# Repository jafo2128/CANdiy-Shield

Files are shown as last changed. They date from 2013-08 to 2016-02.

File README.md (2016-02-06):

# CANdiy-Shield
The CANdiy-Shield is a plug-on module for Arduino/Genuino with CAN-Bus (Controller Area Network) connectivity.

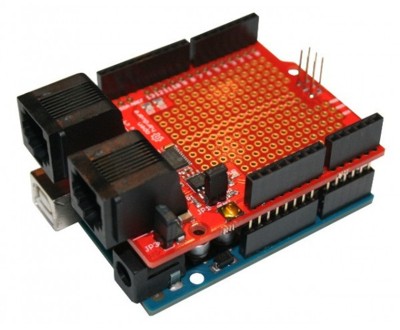
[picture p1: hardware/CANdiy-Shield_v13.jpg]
CANdiy-Shield (http://www.watterott.com/en/Arduino-CANdiy-Shield)


## Shop
* [CANdiy-Shield](http://www.watterott.com/en/Arduino-CANdiy-Shield)
* [Railuino Components](http://www.watterott.com/en/Railuino-components)
* [OBD2-Connector](http://www.watterott.com/en/OBD2-Connector-With-PCB)

## Features
* Microchip MCP2515 CAN Controller (SPI)
* Microchip MCP2562 CAN Transceiver (CANdiy-Shield v1.x: MCP2551)
* Switchable between 3V3 or 5V logic level
* 2 CAN connectors (RJ45)
* Prototyping Area
* Compatible with all Arduino/Genuino Boards (SPI connection via 6-Pin ISP connector)

## Hardware and Software
* [Schematics + Layout](https://github.com/watterott/CANdiy-Shield/tree/master/hardware)
* [Arduino Library and Examples](https://github.com/watterott/Arduino-Libs)

## Projects
* Railuino (Maerklin Model Railways): http://code.google.com/p/railuino/
  [German Documentation](https://railuino.googlecode.com/files/2013-08-01-Railuino-Directors-Cut.pdf),
  [German Forum](http://www.stummiforum.de/viewtopic.php?t=90072),
  [German Magazine Article](https://shop.heise.de/katalog/ct-hardware-hacks-1-2013),
  [English Documentation](http://www.yaasan.mints.ne.jp/railuino.html),
  [French Documentation](http://mchobby.be/wiki/index.php?title=Railuino)
* Mechanic (OBD-II Interface): http://code.google.com/p/mechanic/
* Electricity on Tap: http://www.terabatt.com/makerscorner.html
* WikiCAN (OBD On-Board-Diagnostics): http://www.wikican.uni-bayreuth.de/wikican/index.php?title=WikiCAN-Arduino
* MERG CBUS (Model Railways): http://www.oscale.net/cbus http://www.merg.org.uk/merg_resources/cbus.php

Finally words from us Archivers and Developers.. 

##### Donate

People from time to time wish to donate a little money. Donating won't get you anything special, other than a warm feeling inside, and possibly urge me to produce more freely available material for interesting projects. You can donate via [PayPal](https://www.paypal.com), just click [donate](https://www.paypal.com/cgi-bin/webscr?cmd=_s-xclick&hosted_button_id=3PXVSLXFBS45E) button available below - it will redirect you to the secured PayPal page where you can provide donation amount (there is no minimal value). Any donations are apreciated greatly, and we thank you all in advance for your support along the ways..



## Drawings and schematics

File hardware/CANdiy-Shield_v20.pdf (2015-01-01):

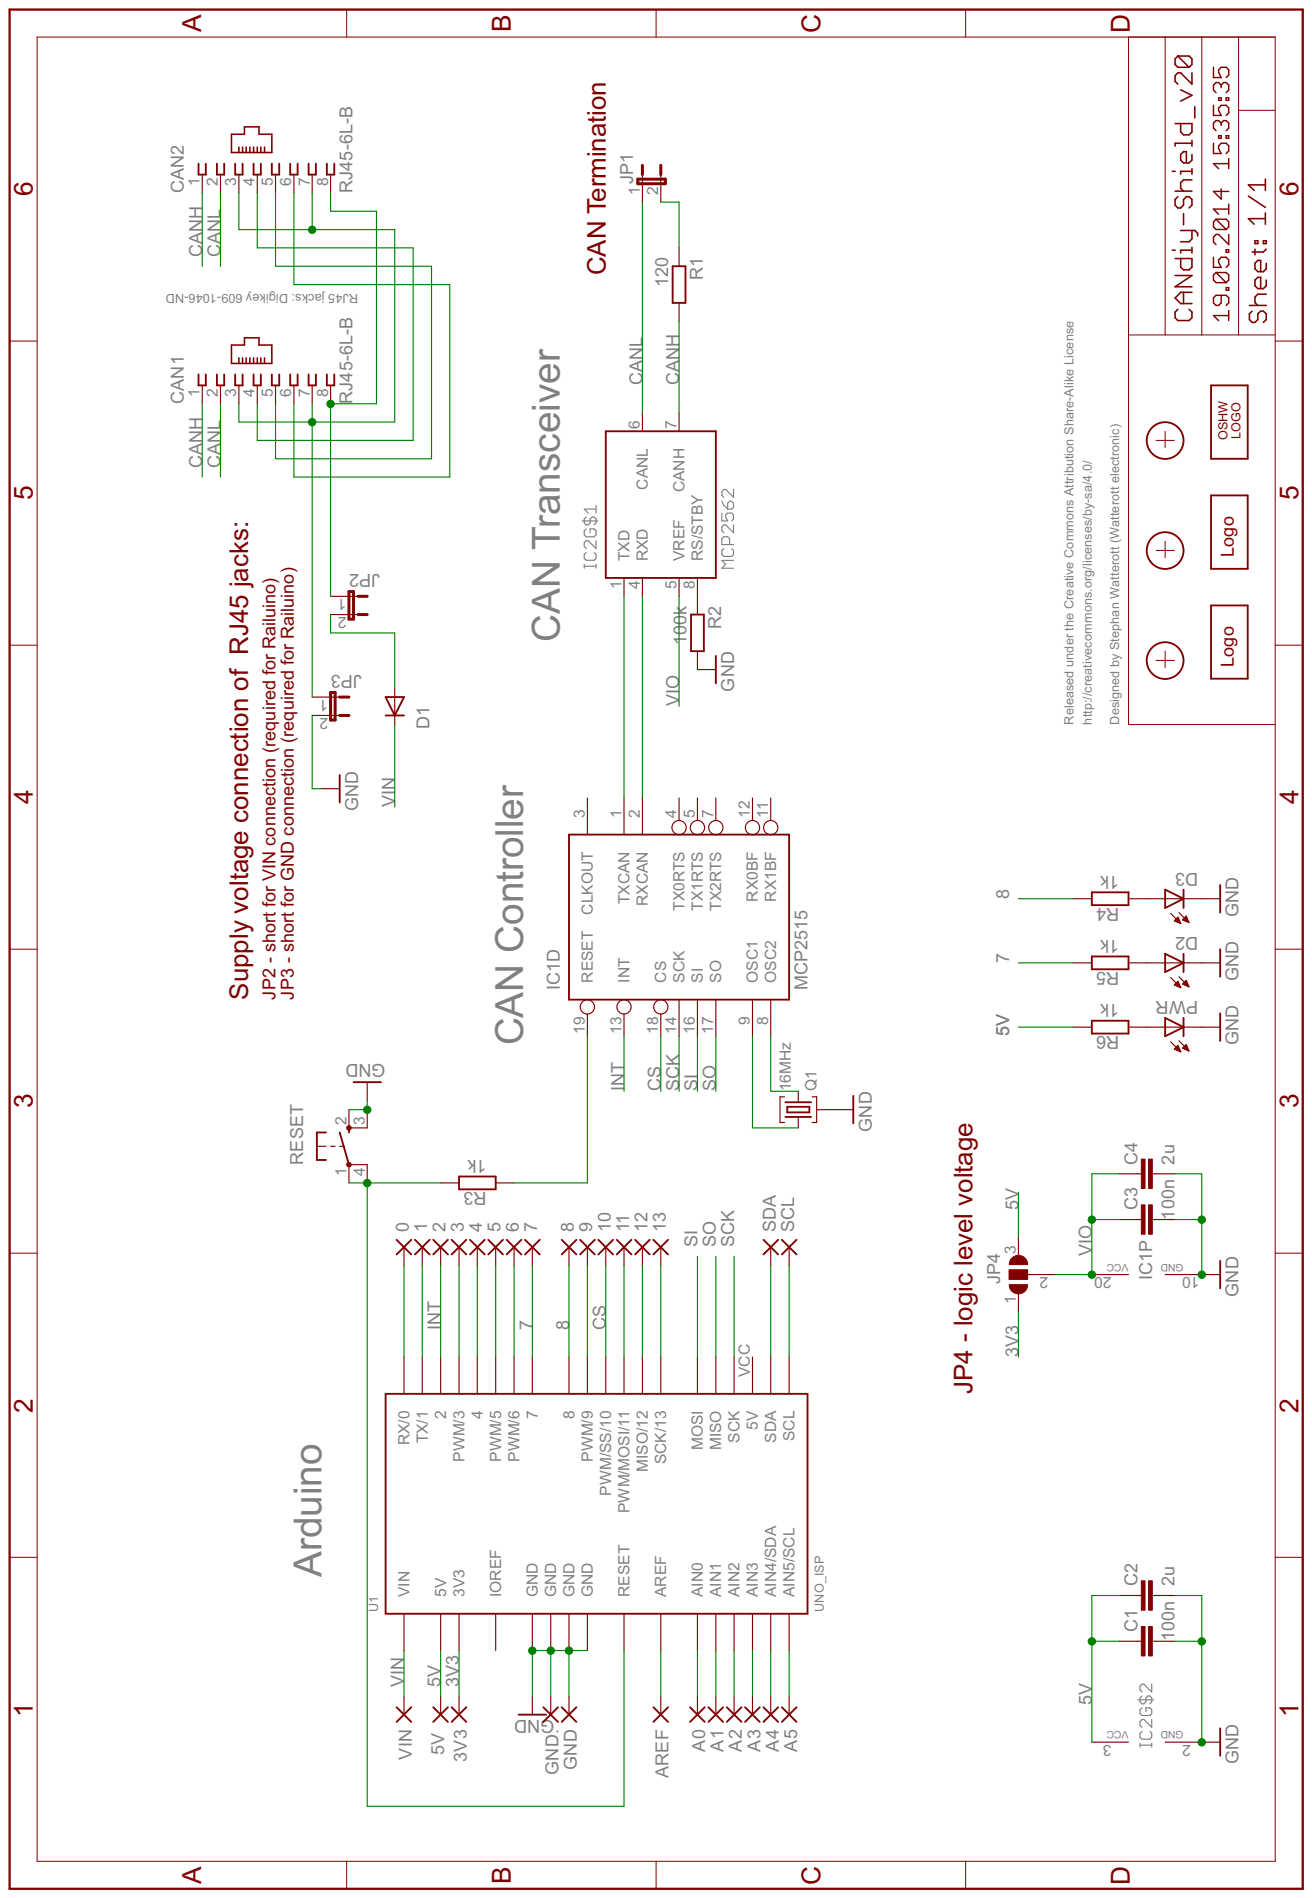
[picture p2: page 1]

DN- 6401- 906 yeki gi D: skcaj 54J RDNG DNG GND 120 RJ45-6L-B RJ45-6L-B 100n 2u GND 100k GND GNDk1 GNDk1 GNDk1 GND 16MHz MCP2515 100n GND 2uk1 Released under the Creative Commons Attribution Share-Alike License http://creativecommons.org/licenses/by-sa/4.0/ Designed by Stephan Watterott (Watterott electronic) Arduino CAN Controller CAN Transceiver /STBY RESET 1 23 4 CANH 7 CANL 6 RS 8 RXD 4 TXD 1 VREF 5 CCV DNG 3 2 R1 CAN2 12345678 CAN1 12345678 C1 C2 R2 JP1 12 2PJ 123PJ 12 012345678910111213SDA SCL A0A1A2A3A4A5 AREF VIN GND GND. 3V3 3D 4R R WP 6R 2D 5R D1 U1 UNO_ISP RX/0 TX/12 AIN0 PWM/34 PWM/5 PWM/678 PWM/9 PWM/SS/10 PWM/MOSI/11 MISO/12 SCK/13 AIN1 AIN2 AIN3 AIN4/SDA AIN5/SCL 5VVIN 3V3 AREF RESET SDA SCL IOREF GND GND GND MOSI MISO SCK GND 5V VCC Q1 IC1D CLKOUT 3 CS 18 INT 13 OSC1 9 OSC2 8 RESET 19 RX0BF 12 RX1BF 11 RXCAN 2 SCK 14 SI 16 SO 17 TX0RTS 4 TX1RTS 5 TX2RTS 7 TXCAN 1 CCV DNG IC1P 02 01 C3 3 1 2 JP4 C4 3R 5V 5V 5V 5V 5V VIN VIN CS CS SCK SCK SI SI SO SO CANH CANH CANH CANL CANL CANL 8 8 INT INT 3V3 3V3 7 7 VIO VIO CAN Termination Supply voltage connection of RJ45 jacks: JP3 - short for GND connection (required for Railuino) JP2 - short for VIN connection (required for Railuino) JP4 - logic level voltage ABCD 1 2 3 4 5 6 ABCD 1 2 3 4 5 6 OSHW LOGO Logo Logo

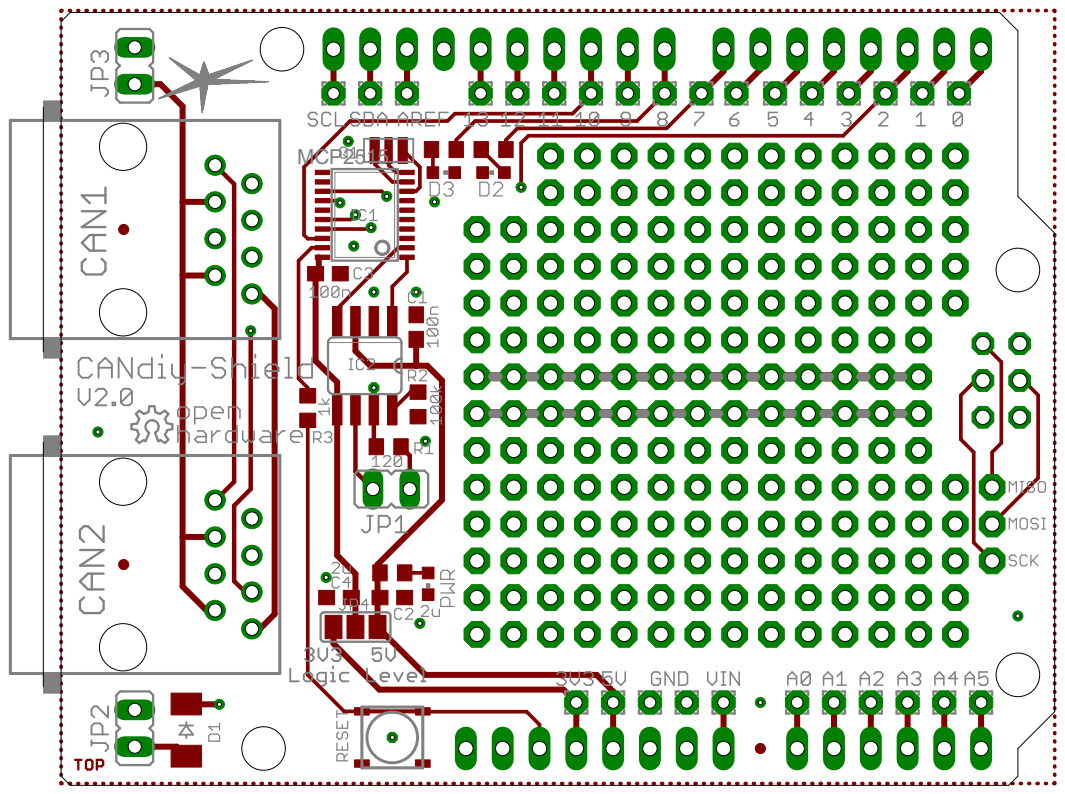
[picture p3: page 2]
MCP2515

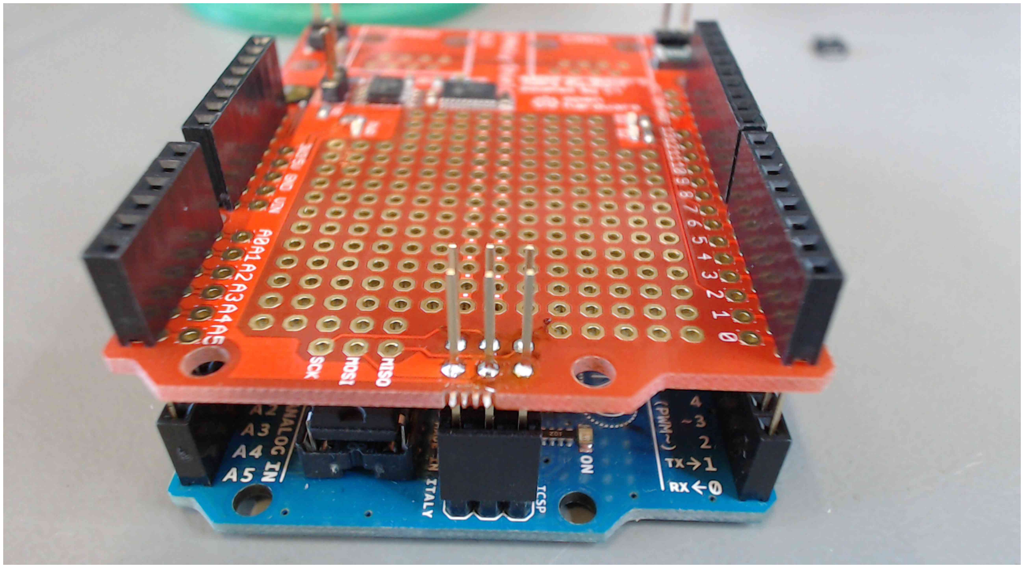
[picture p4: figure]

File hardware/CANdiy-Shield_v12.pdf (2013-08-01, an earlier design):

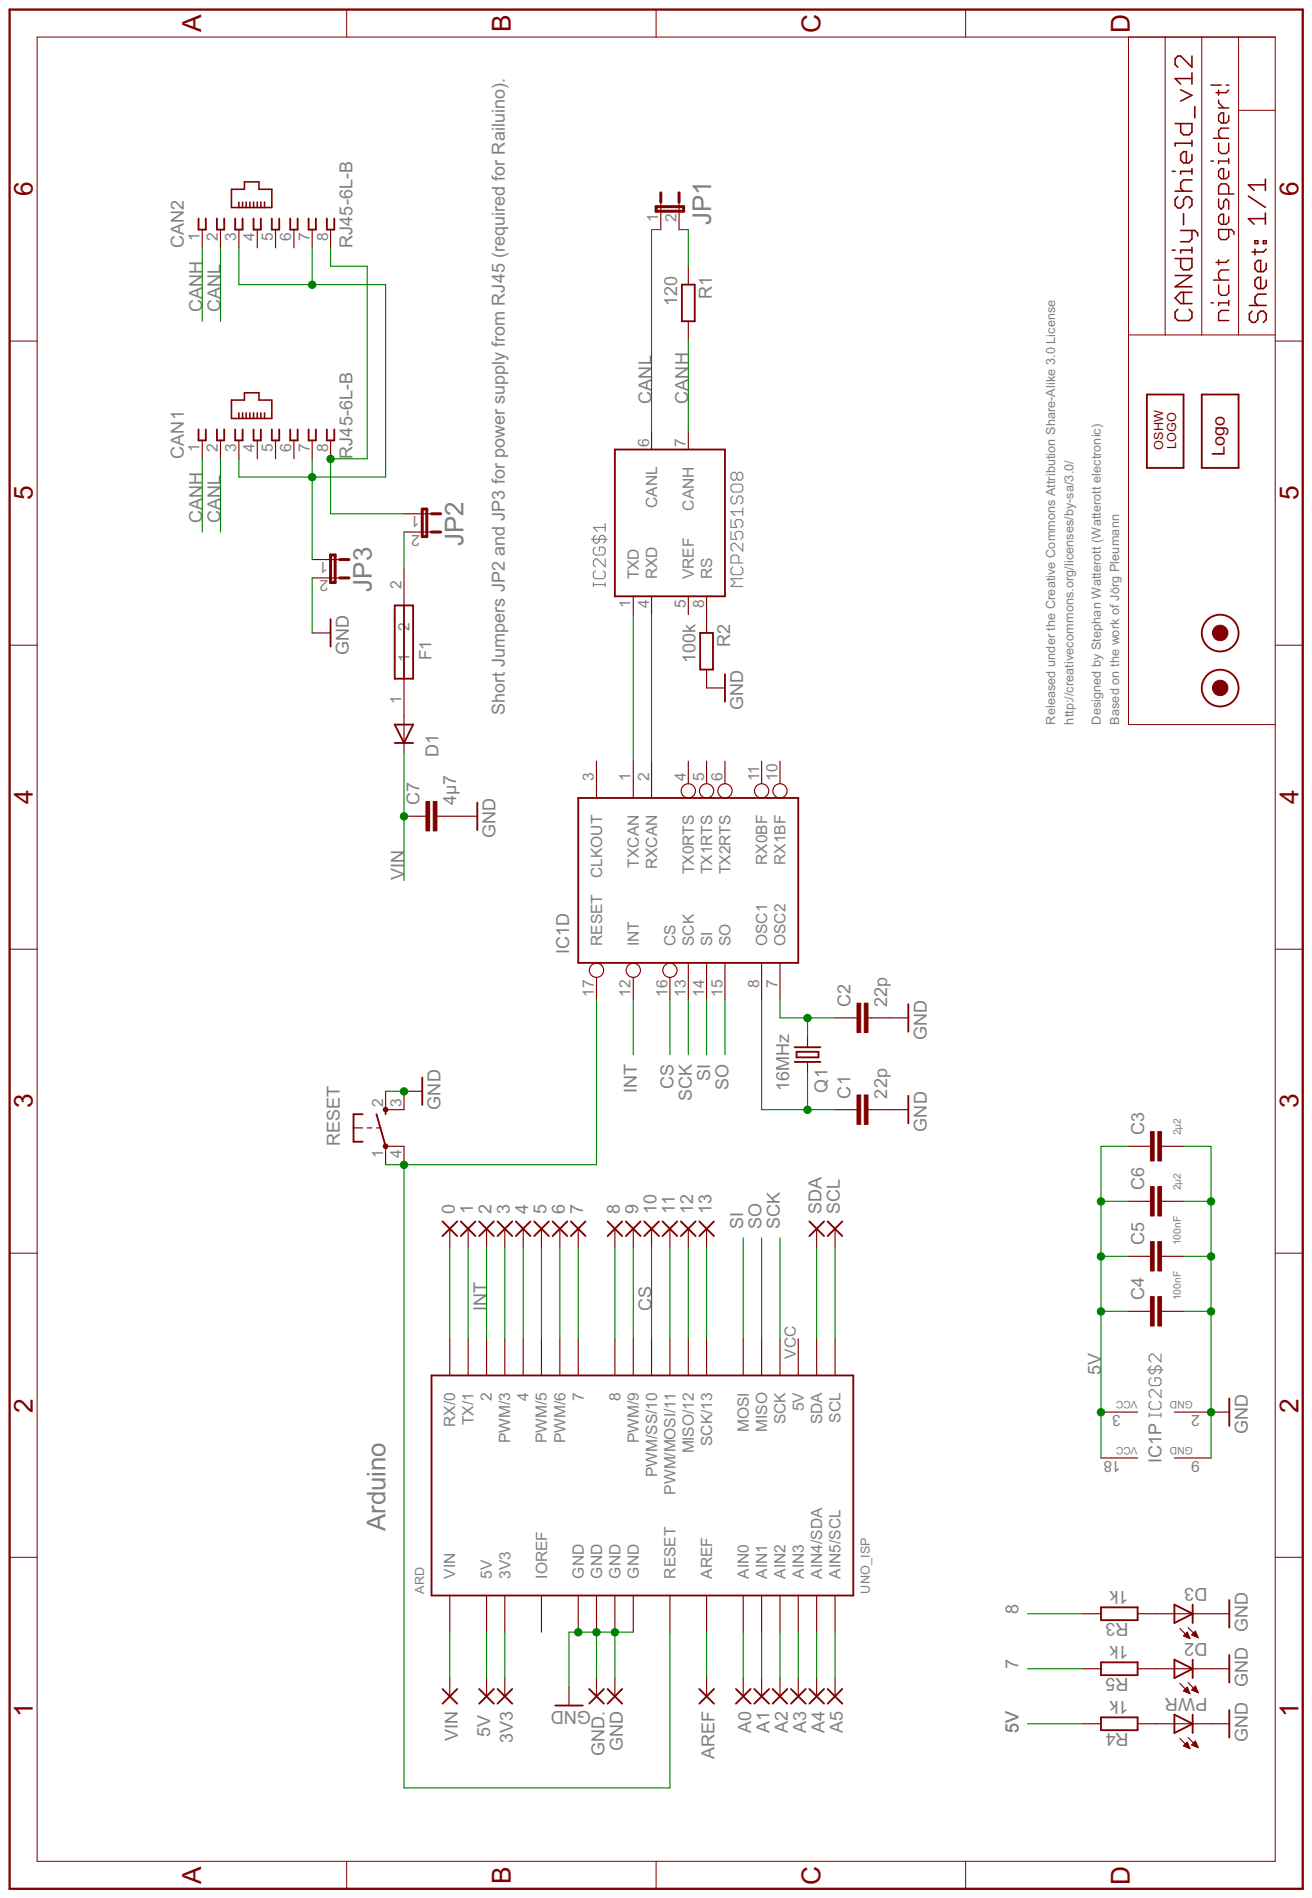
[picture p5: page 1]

GND GND 120 RJ45-6L-B RJ45-6L-B 16MHz 22p 22p 2µ2 100nF 100nF 2µ2 GND GND 100k GND DNG GNDk1 GNDk1 GNDk1 4µ7 GND GND Released under the Creative Commons Attribution Share-Alike 3.0 License http://creativecommons.org/licenses/by-sa/3.0/ Designed by Stephan Watterott (Watterott electronic) Arduino F1 Based on the work of Jörg Pleumann RESET 1 23 4 IC1D CLKOUT 3 CS 16 INT 12 OSC1 8 OSC2 7 RESET 17 RX0BF 11 RX1BF 10 RXCAN 2 SCK 13 SI 14 SO 15 TX0RTS 4 TX1RTS 5 TX2RTS 6 TXCAN 1 CANH 7 CANL 6 RS 8 RXD 4 TXD 1 VREF 5 CCV DNG 3 2 R1 CAN2 12345678 CAN1 12345678 Q1 C1 C2 C3 C4 C5 C6 CCV DNG IC1P 81 9 R2 12JP1 12 JP2 12 JP3 012345678910111213SDA SCL A0A1A2A3A4A5 AREF VIN GND GND. 3V3 3D 3R R WP 4R 2D 5R C7 D1 1 1 2 2 ARD UNO_ISP RX/0 TX/12 AIN0 PWM/34 PWM/5 PWM/678 PWM/9 PWM/SS/10 PWM/MOSI/11 MISO/12 SCK/13 AIN1 AIN2 AIN3 AIN4/SDA AIN5/SCL 5VVIN 3V3 AREF RESET SDA SCL IOREF GND GND GND MOSI MISO SCK GND 5V VCC 5V 5V 5V VIN CS CS SCK SCK SI SI SO SO CANH CANH CANH CANL CANL CANL 8 INT INT 7 ABCD 1 2 3 4 5 6 ABCD 1 2 3 4 5 6 OSHW LOGO Logo Short Jumpers JP2 and JP3 for power supply from RJ45 (required for Railuino).

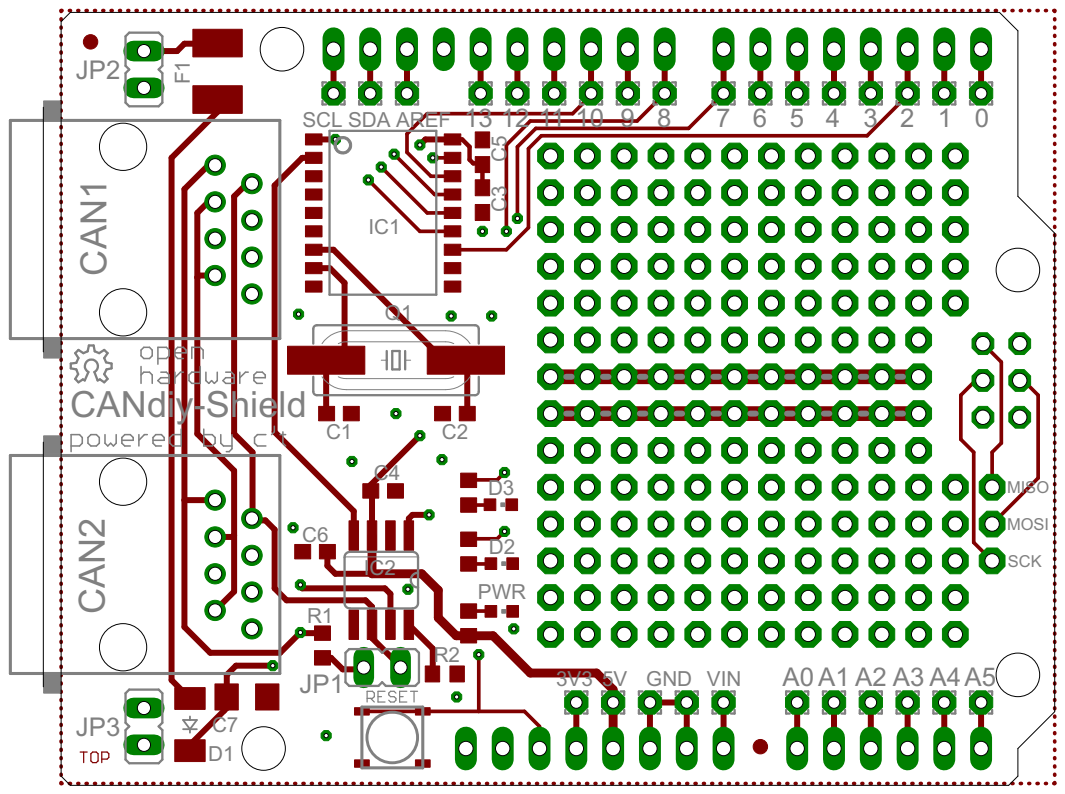
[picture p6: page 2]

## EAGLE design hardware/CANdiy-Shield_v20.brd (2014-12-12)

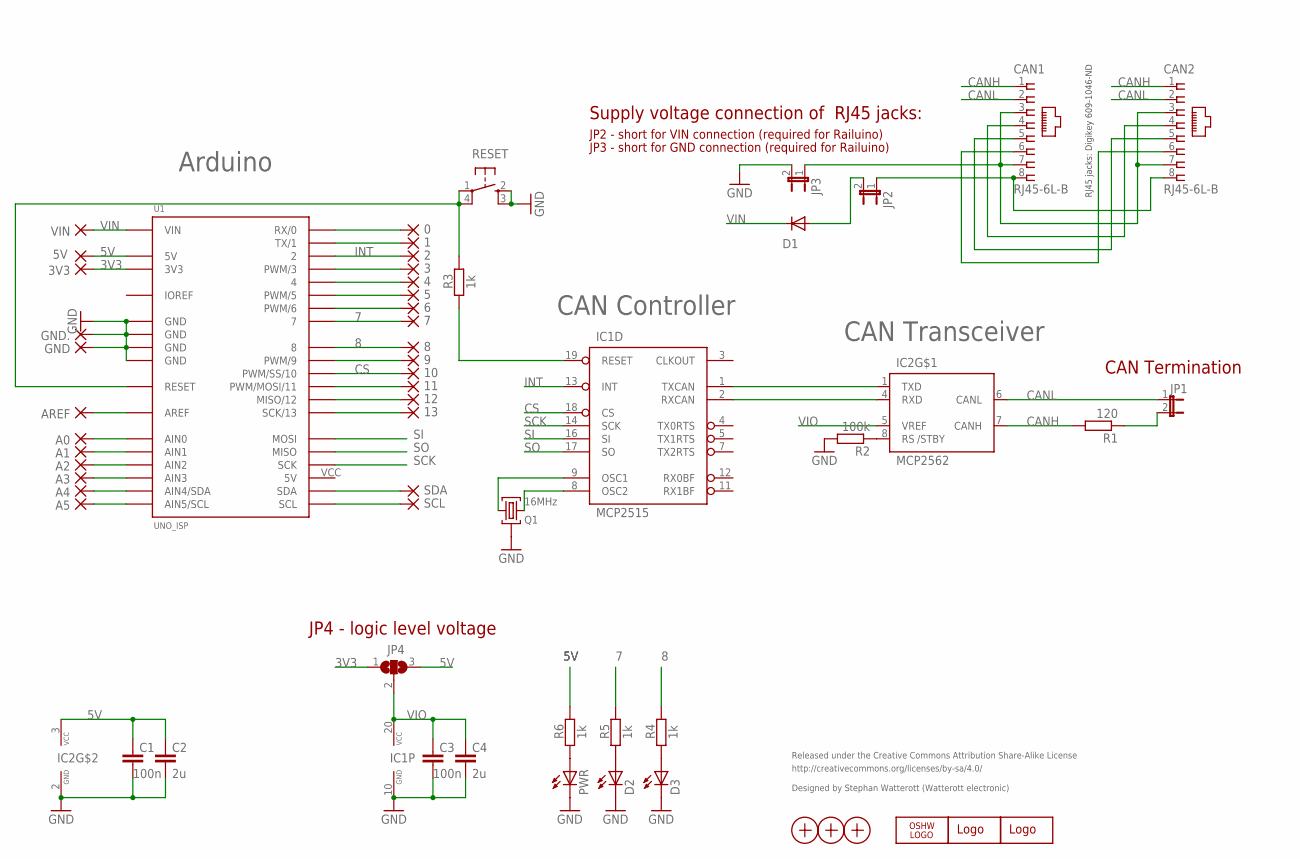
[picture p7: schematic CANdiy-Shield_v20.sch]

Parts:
0, 1, 2, 3, 3V3, 4, 5, 5V, 6, 7, 8, 9, 10, 11, 12, 13: 1,6/0,8
A0, A1, A2, A3, A4, A5: 1,6/0,8
AREF: 1,6/0,8
C1, C3: 100n; C0603
C2, C4: 2u; C0603
CAN1, CAN2: RJ45-6L-B; RJ45-NO-SHIELD
D1: CGRM4001-G; SOD-123_MINI-SMA
D2, D3: LEDCHIPLED_0603; CHIPLED_0603
GND, GND.: 1,6/0,8
IC1: MCP2515; TSSOP20
IC2: MCP2562; SO08
JP1, JP2, JP3: JP1E; JP1
JP4: SJ2W; SJ_2
LOGO1: LOGO-SPARK_PLACE; SPARK_TPLACE
LOGO2: OSHW_LOGO_6MILX0100-NT; OSHW_6X100_NOTEXT
PWR: LEDCHIPLED_0603; CHIPLED_0603
Q1: 16MHz; SMD_OSC_35X15
R1: 120; R0603
R2: 100k; R0603
R3, R4, R5, R6: 1k; R0603
RESET: SW_SMDS; SW_SMD4
SCL: 1,6/0,8
SDA: 1,6/0,8
U1: UNO_ISP
U$1: WE-LOGO
VIN: 1,6/0,8
X1, X2, X3: PASSER

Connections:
0: 0.1, U1.0 (RX/0)
1: 1.1, U1.1 (TX/1)
3: 3.1, U1.3 (PWM/3)
3V3: 3V3.1, JP4.1, U1.3V3
4: 4.1, U1.4
5: 5.1, U1.5 (PWM/5)
5V: 5V.1, C1.1, C2.1, IC2.3 (VCC), JP4.3, R6.1, U1.5V
6: 6.1, U1.6 (PWM/6)
7: 7.1, R5.1, U1.7
8: 8.1, R4.1, U1.8
9: 9.1, U1.9 (PWM/9)
11: 11.1, U1.11 (PWM/MOSI/11)
12: 12.1, U1.12 (MISO/12)
13: 13.1, U1.13 (SCK/13)
A0: A0.1, U1.AIN0
A1: A1.1, U1.AIN1
A2: A2.1, U1.AIN2
A3: A3.1, U1.AIN3
A4: A4.1, U1.AIN4 (AIN4/SDA)
A5: A5.1, U1.AIN5 (AIN5/SCL)
AREF: AREF.1, U1.AREF
CANH: CAN1.1, CAN2.1, IC2.7 (CANH), R1.2
CANL: CAN1.2, CAN2.2, IC2.6 (CANL), JP1.1
CAN_RX: IC1.2 (RXCAN), IC2.4 (RXD)
CAN_TX: IC1.1 (TXCAN), IC2.1 (TXD)
CS: 10.1, IC1.18 (CS), U1.10 (PWM/SS/10)
GND: C1.2, C2.2, C3.2, C4.2, D2.C, D3.C, GND.1, GND..1, IC1.10 (GND), IC2.2 (GND), JP3.2, PWR.C, Q1.GND, R2.2, RESET.2 (S), RESET.3 (S1), U1.GND@1 (GND), U1.GND@2 (GND), U1.GND@3 (GND), U1.GND@4 (GND)
INT: 2.1, IC1.13 (INT), U1.2
IOREF: U1.IOREF
unnamed: IC1.19 (RESET), R3.2
unnamed: CAN1.8, CAN2.8, JP2.1
unnamed: IC2.8 (RS), R2.1
unnamed: CAN1.3, CAN1.7, CAN2.3, CAN2.7, JP3.1
unnamed: JP1.2, R1.1
unnamed: SCL.1, U1.SCL
unnamed: SDA.1, U1.SDA
unnamed: D3.A, R4.2
unnamed: PWR.A, R6.2
unnamed: D2.A, R5.2
unnamed: D1.A, JP2.2
unnamed: CAN1.4, CAN2.4
unnamed: CAN1.5, CAN2.5
unnamed: CAN1.6, CAN2.6
OSC1: IC1.9 (OSC1), Q1.1
OSC2: IC1.8 (OSC2), Q1.2
RESET: R3.1, RESET.1, RESET.4 (P1), U1.RST (RESET)
SCK: IC1.14 (SCK), U1.SCK
SI: IC1.16 (SI), U1.MOSI
SO: IC1.17 (SO), U1.MISO
VIN: D1.C, U1.VIN, VIN.1
VIO: C3.1, C4.1, IC1.20 (VCC), IC2.5 (VREF), JP4.2

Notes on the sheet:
Released under the Creative Commons Attribution Share-Alike License
http://creativecommons.org/licenses/by-sa/4.0/
Designed by Stephan Watterott (Watterott electronic)
Arduino
CAN Termination
Supply voltage connection of RJ45 jacks:
JP3 - short for GND connection (required for Railuino)
JP2 - short for VIN connection (required for Railuino)
RJ45 jacks: Digikey 609-1046-ND
CAN Controller
CAN Transceiver
JP4 - logic level voltage
/STBY

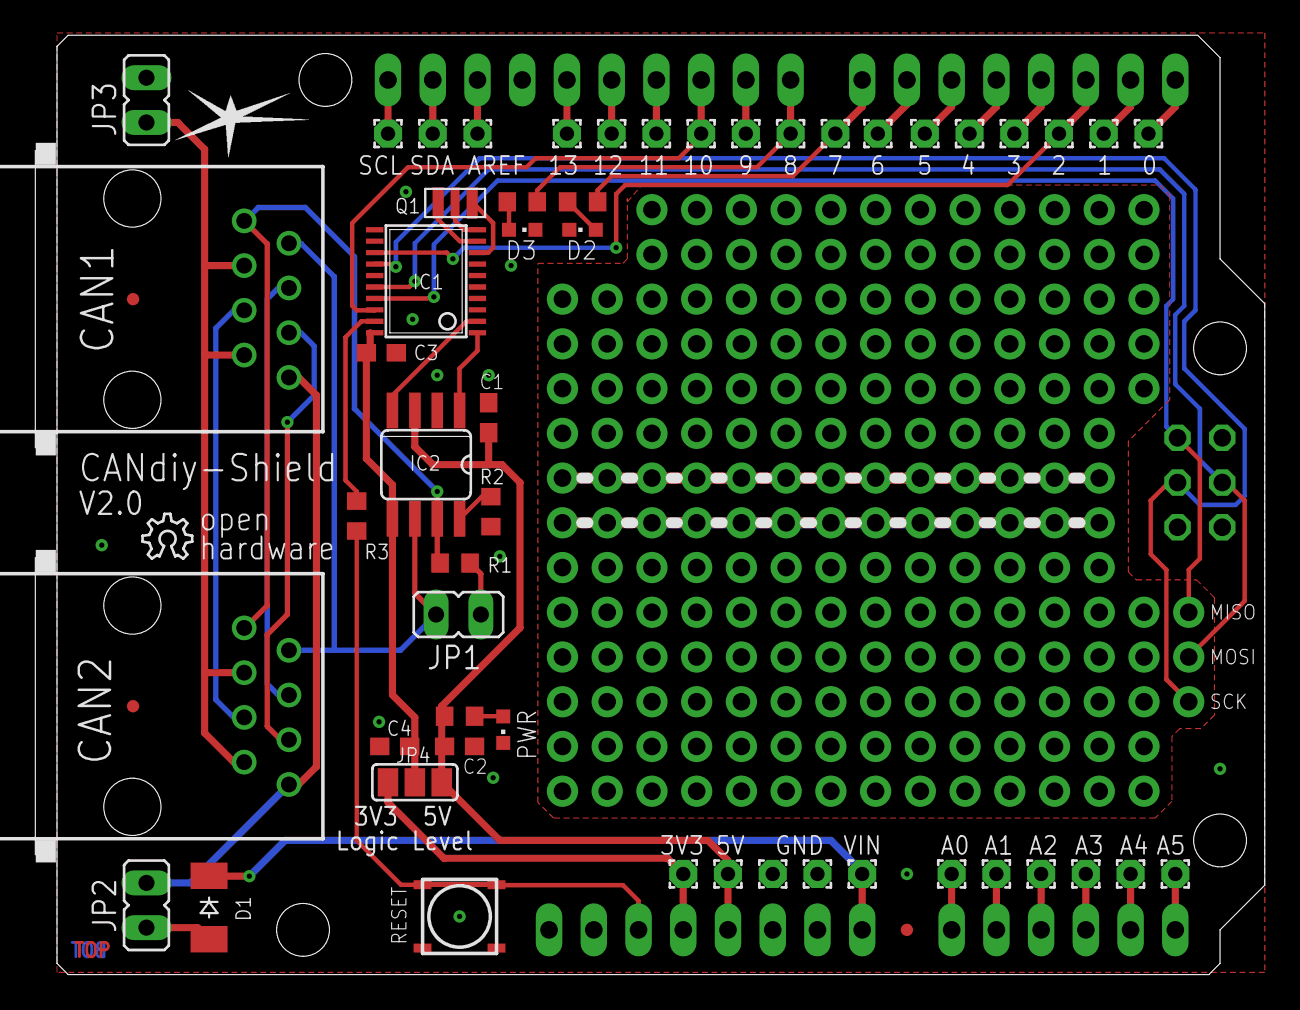
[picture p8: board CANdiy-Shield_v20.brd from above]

Board: 2 copper layers, 69.8 x 53.3 mm, 59 parts (1 on the bottom side), 50 nets.

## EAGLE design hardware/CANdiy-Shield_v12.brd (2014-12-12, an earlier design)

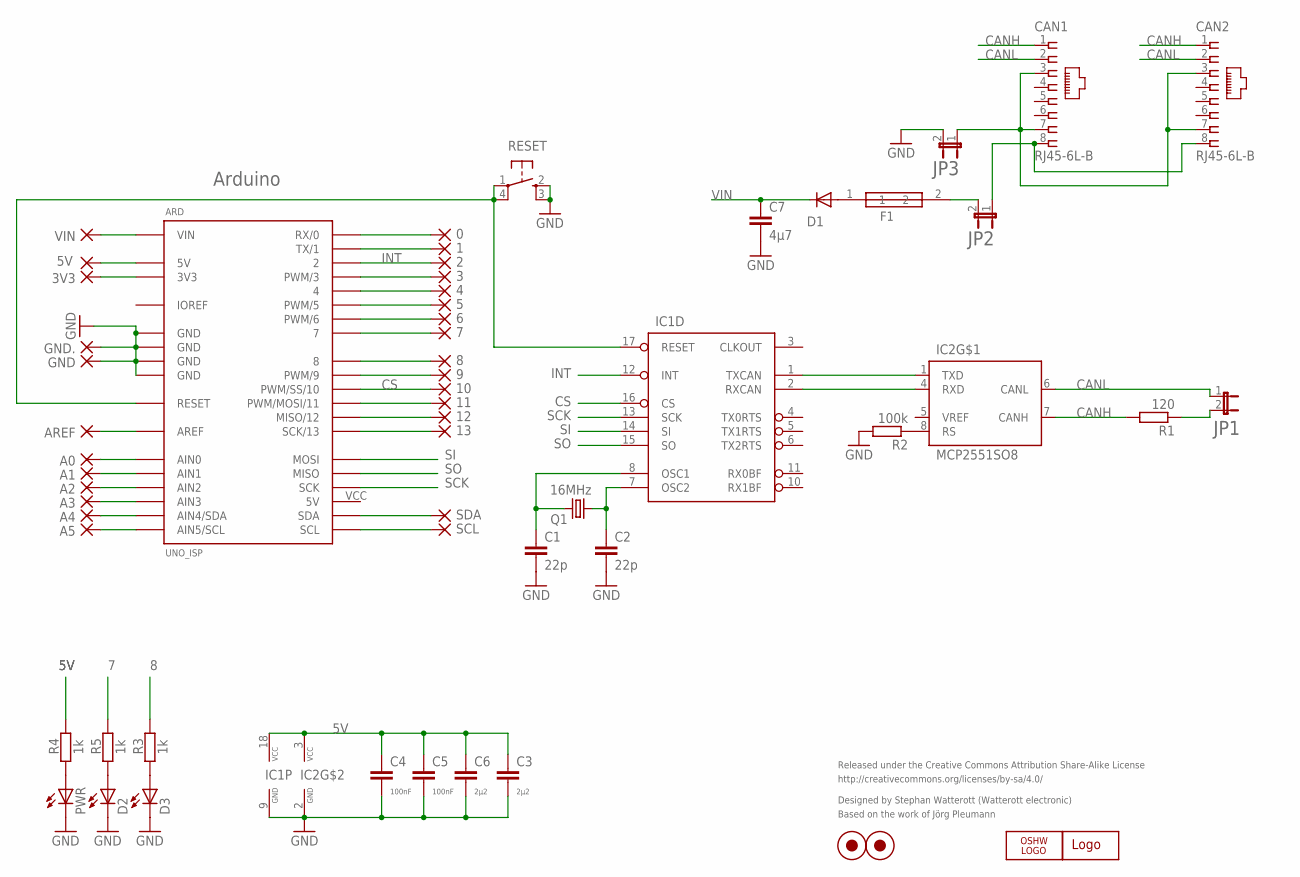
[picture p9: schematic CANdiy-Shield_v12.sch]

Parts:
0, 1, 2, 3, 3V3, 4, 5, 5V, 6, 7, 8, 9, 10, 11, 12, 13: 1,6/0,8
A0, A1, A2, A3, A4, A5: 1,6/0,8
ARD: UNO_ISP
AREF: 1,6/0,8
C1, C2: 22p; C0603
C3, C6: 2µ2; C0603
C4, C5: 100nF; C0603
C7: 4µ7; C1206
CAN1, CAN2: RJ45-6L-B; RJ45-NO-SHIELD
D1: CGRM4001-G; SOD-123_MINI-SMA
D2, D3: LEDCHIPLED_0603; CHIPLED_0603
F1: F1; L1812
GND, GND.: 1,6/0,8
IC1: MCP2515SO; SO-18W
IC2: MCP2551SO8; SO08
JP1, JP2, JP3: JP1E; JP1
LOGO2: OSHW_LOGO_6MILX0100-NT; OSHW_6X100_NOTEXT
PWR: LEDCHIPLED_0603; CHIPLED_0603
Q1: 16MHz; HC49UP
R1: 120; R0603
R2: 100k; R0603
R3, R4, R5: 1k; R0603
RESET: SW_SMDS; SW_SMD4
SCL: 1,6/0,8
SDA: 1,6/0,8
U$1: WE-LOGO
VIN: 1,6/0,8
X_1, X_2: PASS_1MM; ROUND_1MM

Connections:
3V3: 3V3.1, ARD.3V3
5V: 5V.1, ARD.5V, C3.1, C4.1, C5.1, C6.1, IC1.18 (VCC), IC2.3 (VCC), R4.1
7: 7.1, ARD.7, R5.1
8: 8.1, ARD.8, R3.1
9: 9.1, ARD.9 (PWM/9)
A0: A0.1, ARD.AIN0
AERF: ARD.AREF, AREF.1
CANH: CAN1.1, CAN2.1, IC2.7 (CANH), R1.2
CANL: CAN1.2, CAN2.2, IC2.6 (CANL), JP1.1
CS: 10.1, ARD.10 (PWM/SS/10), IC1.16 (CS)
GND: ARD.GND@1 (GND), ARD.GND@2 (GND), ARD.GND@3 (GND), ARD.GND@4 (GND), C1.2, C2.2, C3.2, C4.2, C5.2, C6.2, C7.2, D2.C, D3.C, GND.1, GND..1, IC1.9 (GND), IC2.2 (GND), JP3.2, PWR.C, R2.2, RESET.2 (S), RESET.3 (S1)
INT: 2.1, ARD.2, IC1.12 (INT)
IOREF: ARD.IOREF
unnamed: C2.1, IC1.7 (OSC2), Q1.1
unnamed: C1.1, IC1.8 (OSC1), Q1.2
unnamed: CAN1.8, CAN2.8, JP2.1
unnamed: IC2.8 (RS), R2.1
unnamed: CAN1.3, CAN1.7, CAN2.3, CAN2.7, JP3.1
unnamed: JP1.2, R1.1
unnamed: ARD.SCL, SCL.1
unnamed: ARD.SDA, SDA.1
unnamed: D3.A, R3.2
unnamed: PWR.A, R4.2
unnamed: D2.A, R5.2
unnamed: 11.1, ARD.11 (PWM/MOSI/11)
unnamed: 12.1, ARD.12 (MISO/12)
unnamed: 13.1, ARD.13 (SCK/13)
unnamed: 6.1, ARD.6 (PWM/6)
unnamed: 5.1, ARD.5 (PWM/5)
unnamed: 4.1, ARD.4
unnamed: 3.1, ARD.3 (PWM/3)
unnamed: 1.1, ARD.1 (TX/1)
unnamed: 0.1, ARD.0 (RX/0)
unnamed: A1.1, ARD.AIN1
unnamed: A2.1, ARD.AIN2
unnamed: A3.1, ARD.AIN3
unnamed: A4.1, ARD.AIN4 (AIN4/SDA)
unnamed: A5.1, ARD.AIN5 (AIN5/SCL)
unnamed: D1.A, F1.1
unnamed: F1.2, JP2.2
RESET: ARD.RST (RESET), IC1.17 (RESET), RESET.1, RESET.4 (P1)
RXCAN: IC1.2 (RXCAN), IC2.4 (RXD)
SCK: ARD.SCK, IC1.13 (SCK)
SI: ARD.MOSI, IC1.14 (SI)
SO: ARD.MISO, IC1.15 (SO)
TXCAN: IC1.1 (TXCAN), IC2.1 (TXD)
VIN: ARD.VIN, C7.1, D1.C, VIN.1

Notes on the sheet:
Released under the Creative Commons Attribution Share-Alike License
http://creativecommons.org/licenses/by-sa/4.0/
Designed by Stephan Watterott (Watterott electronic)
Arduino
Based on the work of Jörg Pleumann

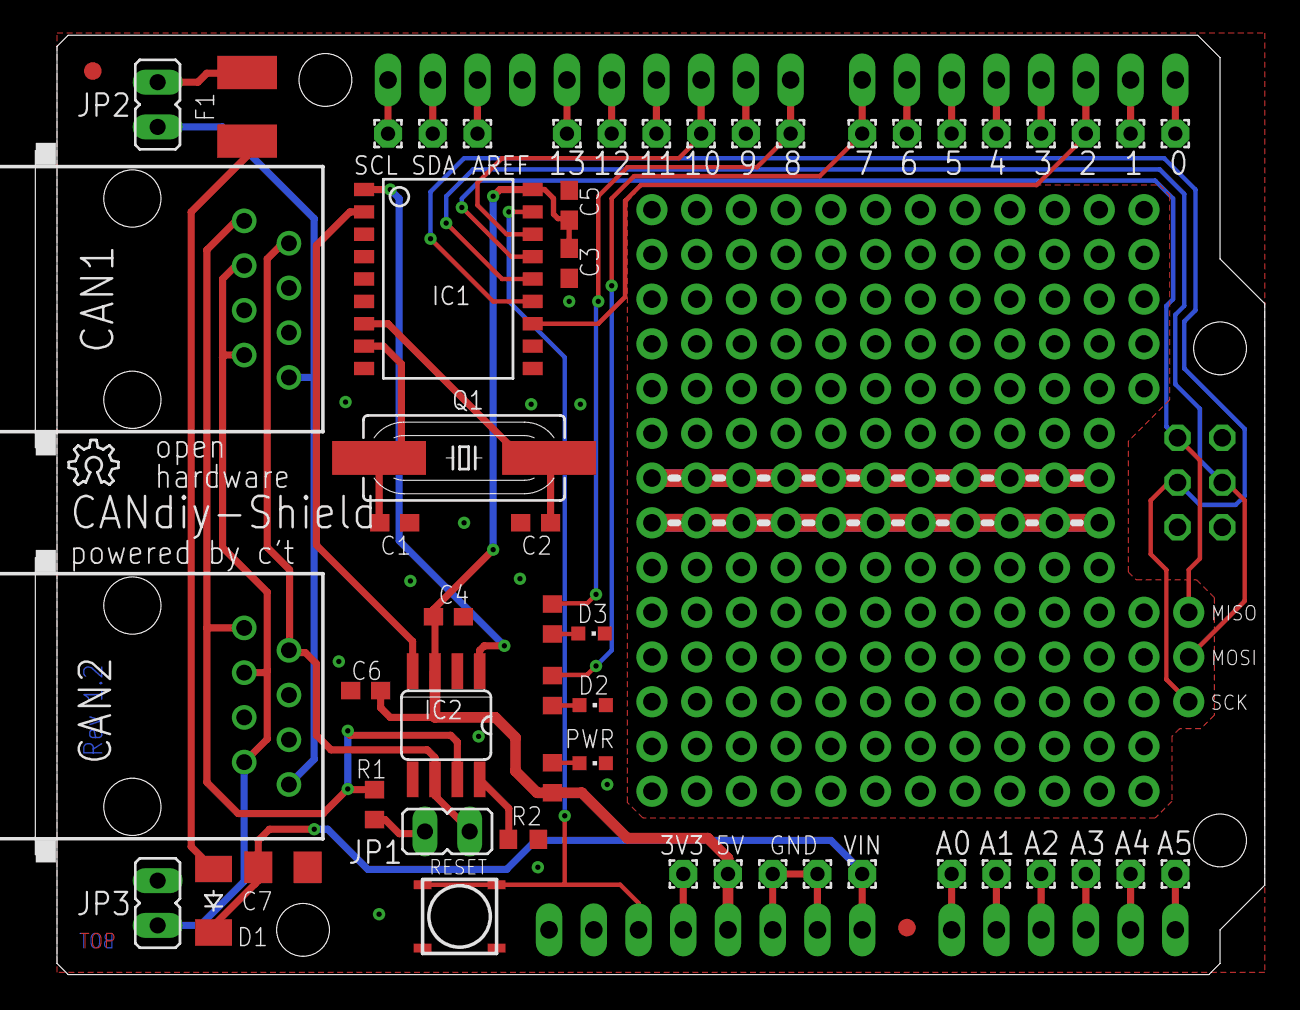
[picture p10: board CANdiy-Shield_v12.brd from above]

Board: 2 copper layers, 69.8 x 53.3 mm, 59 parts (1 on the bottom side), 46 nets.

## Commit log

2013-02-21 added schematics and layout
    [CANdiy-Shield_v12.brd, CANdiy-Shield_v12.sch]
2013-04-28 added Arduino example and MCP2515 lib
2013-06-10 added jumper infos
    [CANdiy-Shield_v12.sch]
2013-08-01 updated pcb
    [CANdiy-Shield_v13.brd, CANdiy-Shield_v13.sch]
2014-01-02 moved examples to Arduino-Libs repository
2014-04-19 updated schematics and layout files
    [CANdiy-Shield_v12.sch, CANdiy-Shield_v13.sch]
2014-05-13 added infos for connectors
2014-06-11 added v2.0 schematics and layout
    [CANdiy-Shield_v20.brd, CANdiy-Shield_v20.sch]
2014-08-21 updated layout and schematics
    [CANdiy-Shield_v12.brd, CANdiy-Shield_v13.brd, CANdiy-Shield_v20.brd]
2014-11-06 cleaned up schematics and layout
    [CANdiy-Shield_v12.brd, CANdiy-Shield_v12.sch, CANdiy-Shield_v13.brd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]
2015-01-01 updated schematics
2015-08-21 changed path structure
    [CANdiy-Shield_v12.brd, CANdiy-Shield_v12.sch, CANdiy-Shield_v13.brd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]
